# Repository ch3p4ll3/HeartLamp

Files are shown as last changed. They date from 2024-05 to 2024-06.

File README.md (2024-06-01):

# Heart Lamp
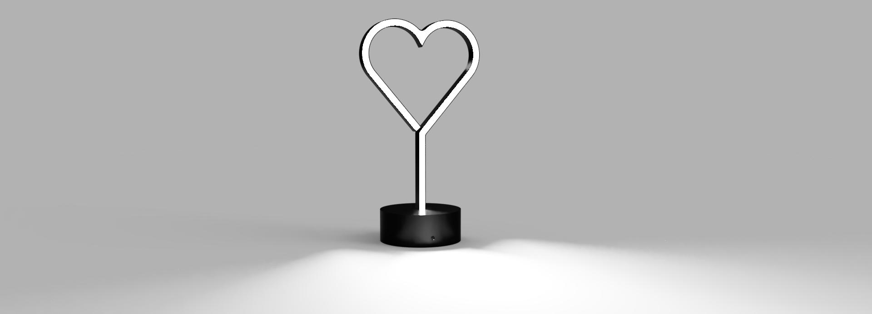
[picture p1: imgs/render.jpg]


This repository contains all the necessary files and instructions to build a heart-shaped lamp that can be controlled via WiFi and IR receiver. The lamp is based on the WEMOS D1 Mini board with WLED firmware and features a unique heart-shaped design.

# Table of contents
- [Heart Lamp](#heart-lamp)
- [Table of contents](#table-of-contents)
- [Features](#features)
- [Assembly Instructions](#assembly-instructions)
  - [3D Printing](#3d-printing)
  - [Electronics](#electronics)
    - [BOM](#bom)
    - [Schematics](#schematics)
    - [ESP Firmware](#esp-firmware)
  - [Final assembly](#final-assembly)
- [Photos](#photos)
- [Future updates](#future-updates)

# Features
- WiFi Control: Easily control the lamp via WiFi using the WLED mobile app or web interface.
- IR Receiver: Allows control of the lamp using an infrared remote control.
- Customizable: The lamp design can be customized to fit your preferences.
- Easy Assembly: Simple assembly process with detailed instructions.
- Powered via USB-C
- Supports 5V, 9V, 12V, 15V, 20V led strips
- Thanks to USB-C's PD protocol, you can select the right voltage for your LED strips(JP2). Be carefull selecting the right voltage or you might destroy the leds!

# Assembly Instructions

## 3D Printing

Print all 3 files, be careful: the stem may be too long for the printing plane, you may need to position it at 45° or print it at a slight angle. For the base, you may need to use the supports.

## Electronics

### BOM
| Part | Value | Device | Description | Link |
|---|---|---|---|---|
| C1 | 1uF | C_CHIP-0603(1608-METRIC) | Capacitor - Generic | [Link](https://it.aliexpress.com/item/1005006157020955.html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) |
| IC1 | TSOP38238 | TSOP38238 | IR Remote Receiver 38KHz 45m | [Link](https://it.aliexpress.com/item/1005005343344128.html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) |
| IC3 | CH224K | CH224K | ESSOP-10 USB ICs ROHS | [Link](https://it.aliexpress.com/item/1005006017022405.html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) |
| J1 | B4B-XH-A | B4B-XH-A | XH Connector Top Entry - 4POS | [Link](https://it.aliexpress.com/item/1005005183951296.html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) |
| J2 | B6B-XH-A_LF__SN_ | B6B-XH-A_LF__SN_ | CONN HEADER VERT 6POS 2.5MM | [Link](https://it.aliexpress.com/item/33005202279.html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) |
| JP2 | PINHD-2X3 | PINHD-2X3 | PIN HEADER | [Link](https://it.aliexpress.com/item/1005006112365881.html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) |
| PS1 | K7803JT-500R3-LB | K7803JT-500R3-LB | LINEAR REGULATOR REPLACEMENT DC Non-Isolated PoL Module DC DC Converter 1 Output 3.3V - - - 500mA 4.75V - 36V Input | [Link](https://it.aliexpress.com/item/1005004632042233.html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) |
| Q1 | IRLZ44N | IRLZ44N | MOSFET MOSFET, 55V, 41A, 22 mOhm, 32 nC Qg, Logic Level, TO-220AB | [Link](https://it.aliexpress.com/item/1005004533156263.html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) |
| Q2 | IRLZ44N | IRLZ44N | MOSFET MOSFET, 55V, 41A, 22 mOhm, 32 nC Qg, Logic Level, TO-220AB | [Link](https://it.aliexpress.com/item/1005004533156263.html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) |
| Q3 | IRLZ44N | IRLZ44N | MOSFET MOSFET, 55V, 41A, 22 mOhm, 32 nC Qg, Logic Level, TO-220AB | [Link](https://it.aliexpress.com/item/1005004533156263.html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) |
| R1 | 10k | R_AXIAL-7.2MM-PITCH | Resistor Fixed - Generic | [Link](https://it.aliexpress.com/item/1005006706426367.html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) |
| R2 | 10k | R_AXIAL-7.2MM-PITCH | Resistor Fixed - Generic | [Link](https://it.aliexpress.com/item/1005006706426367.html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) |
| R3 | 10k | R_AXIAL-7.2MM-PITCH | Resistor Fixed - Generic | [Link](https://it.aliexpress.com/item/1005006706426367.html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) |
| R4 | 10K | R_CHIP-0603(1608-METRIC) | Resistor Fixed - Generic | [Link](https://it.aliexpress.com/item/1005006157071739.html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) |
| R5 | 10k | R_CHIP-0603(1608-METRIC) | Resistor Fixed - Generic | [Link](https://it.aliexpress.com/item/1005006157071739.html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) |
| R6 | 10k | R_CHIP-0603(1608-METRIC) | Resistor Fixed - Generic | [Link](https://it.aliexpress.com/item/1005006157071739.html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) |
| R7 | 10k | R_CHIP-0603(1608-METRIC) | Resistor Fixed - Generic | [Link](https://it.aliexpress.com/item/1005006157071739.html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) |
| R8 | 1K | R_CHIP-0603(1608-METRIC) | Resistor Fixed - Generic | [Link](https://it.aliexpress.com/item/1005006157071739.html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) |
| WEMOS1 |  | WEMOS-D1-MINI | WeMos.cc | [Link](https://it.aliexpress.com/item/1005006365878568.html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) |
| USB-C |  | USB-C 6 pin connector |  | [Link](https://it.aliexpress.com/item/1005005996991234.html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) |
| LED strip |  | LED strip |  | [Link](https://it.aliexpress.com/item/1005005467162038.html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) |

### Schematics

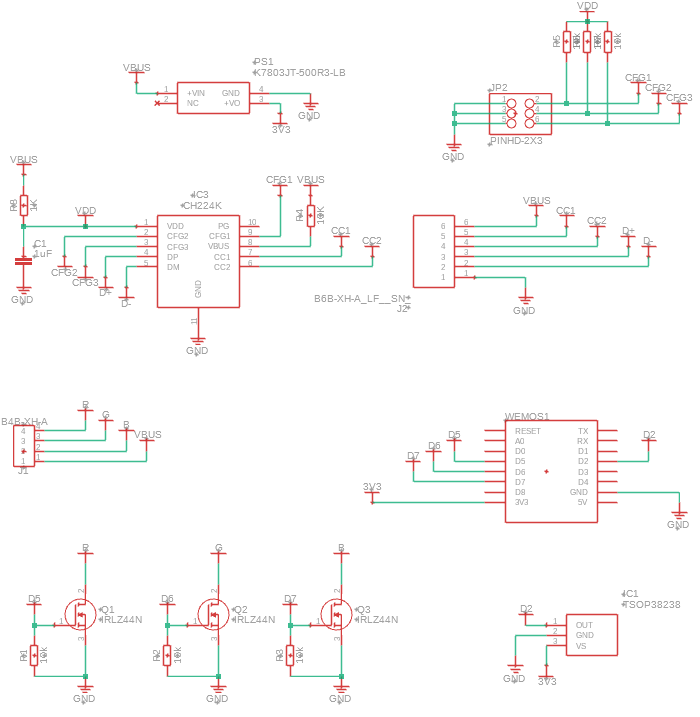
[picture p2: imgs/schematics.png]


### ESP Firmware

Follow the WLED [official guide](https://kno.wled.ge/basics/install-binary/) to install the firmware. I recommend to use the [installer site](https://install.wled.me/).

Once installed enter the WLED interface, select settings -> LED Preferences:
- On Hardware setup select `PWM RGB` and set the GPIOs to **12**, **13**, **14**
- Scroll down slightly to `IR GPIO` and set the value to **4** and **24-Key RGB**
- Click save

## Final assembly

Once you have printed all the files and soldered the various components to the PCB proceed by following the steps: 

- Gluing the LED strip inside the stem channel. Remember to cut the LED strip where indicated, the total length should be approximately 50cm
- Desolder the old connector from the LEDs and solder 4 new wires. Keep in mind what is the cable that carries the power(called 5v on the led strip)
- Crimp the XH2.54 female connector to the 4 wires keeping in mind that the top pin(the one closest to the IR sensor) should be the power supply for the LEDs. The other cables can also be crimped in another sequence, it will be possible to remap them later on the WEB interface
- (Optional) To increase the mechanical strength of the led strip near the soldering coat with hot glue
- Stick the stem inside the base, the stem should go in with a little force
- Insert the PCB inside the base and connect the LEDs
- Try turning on the lamp on by powering it through the usb-c connector and check that everything is ok
- Close the lamp by snapping the cover on. congratulations. your lamp is now working

# Photos

| | |
| - | - |
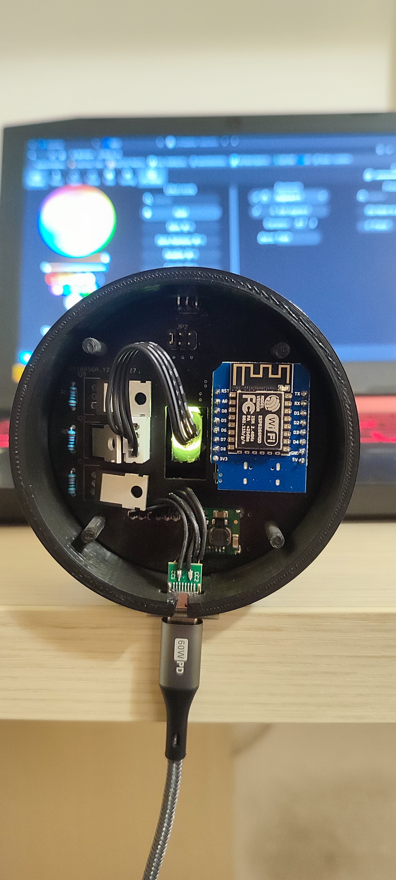
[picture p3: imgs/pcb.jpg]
pcb
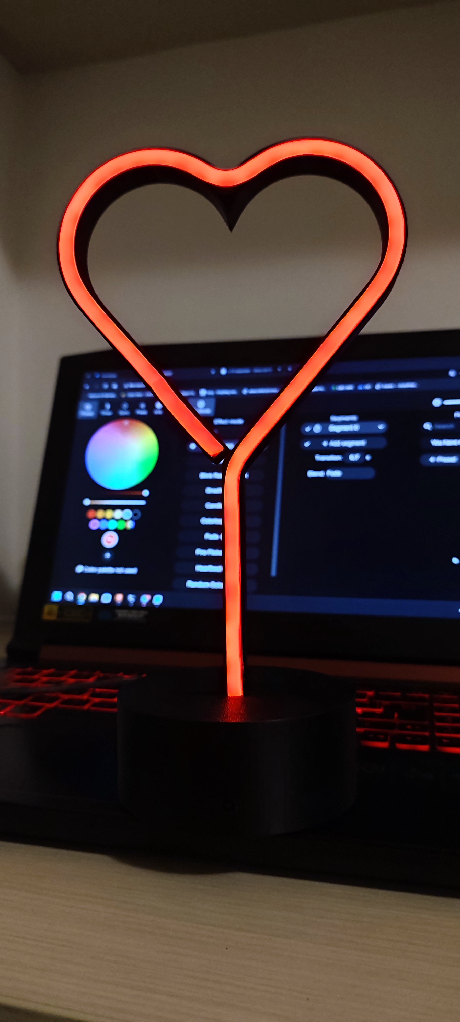
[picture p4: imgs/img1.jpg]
|  |  |
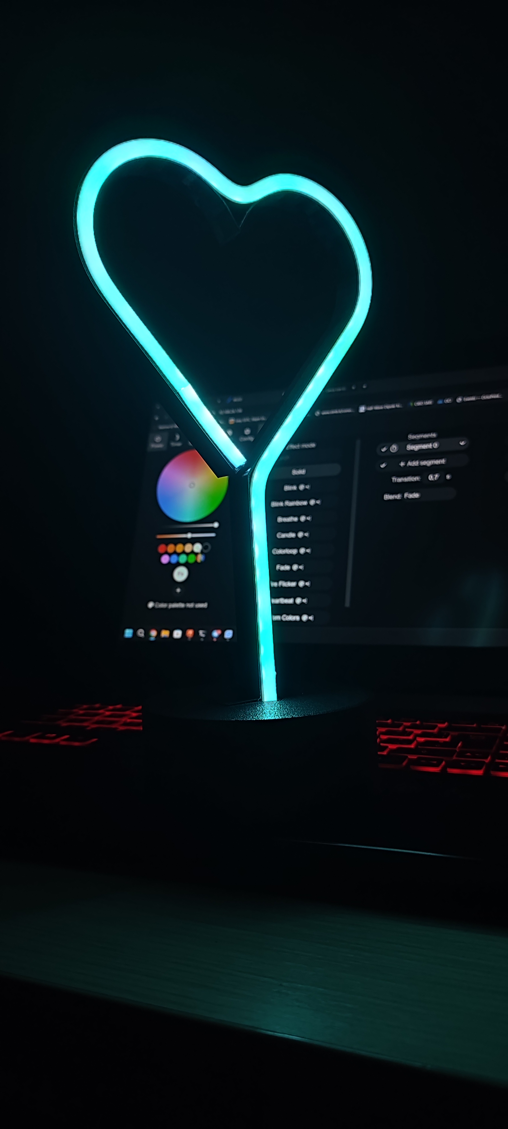
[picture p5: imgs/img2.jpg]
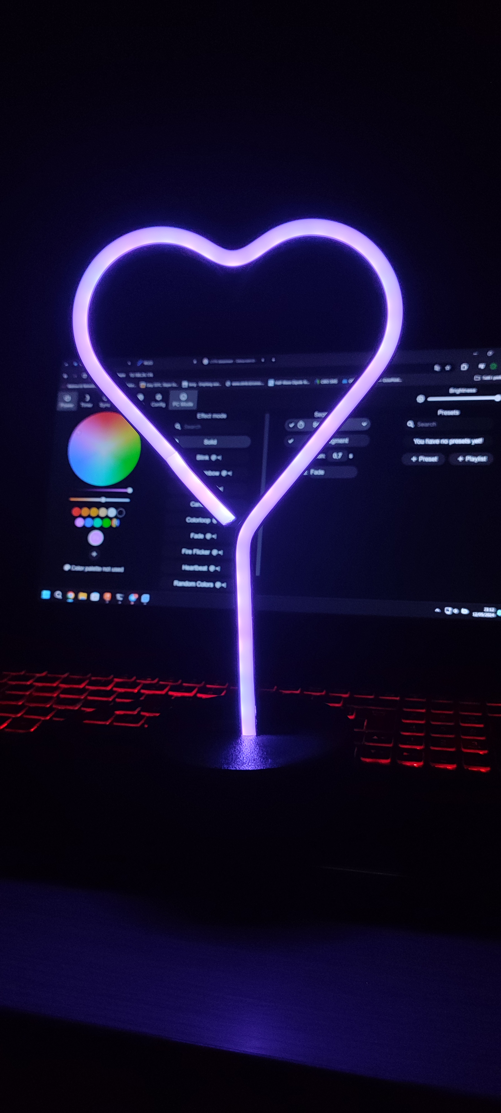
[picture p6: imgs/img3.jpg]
|  |  |

# Future updates
- Use SMD mosfets
- Create other shapes

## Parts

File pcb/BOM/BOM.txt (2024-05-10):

Partlist exported from C:/Users/vido2/AppData/Local/Temp/Neutron/ElectronFileOutput/12116/sch-47e98def-c98e-496b-b999-fb76e8bc99ff/Schema v21.sch at 11/05/2024 00:43

Part   Value            Device                   Package                        Description                                                                                                         ARROW_PART_NUMBER ARROW_PRICE-STOCK                                                                CATEGORY  DESCRIPTION                                                                                                         DSECRIPTION                                               HEIGHT MANUFACTURER           MANUFACTURER_NAME                MANUFACTURER_PART_NUMBER MOUSER_PART_NUMBER MOUSER_PRICE-STOCK                                                                                     MPN              OPERATING_TEMP OPERATING_TEMPERATURE PART_STATUS PITCH            RATING ROHS_COMPLIANCE  ROHS_COMPLIANT SERIES  SUB-CATEGORY       SUB_CATEGORY            THERMALLOSS TOLERANCE TYPE                                                        VOLTAGE_RATING
C1     1uF              C_CHIP-0603(1608-METRIC) CAPC1608X85                    Capacitor - Generic                                                                                                                                                                                                    Capacitor                                                                                                                                                                                                                                                                                                                                                                                                                                                                                                                                                                                                                                                                              
IC1    TSOP38238        TSOP38238                TSOP38238                      IR Remote Receiver 38KHz 45m                                                                                        TSOP38238         https://www.arrow.com/en/products/tsop38238/vishay?region=nac                              IR Remote Receiver 38KHz 45m                                                                                                                                                  mm                            Vishay                           TSOP38238                782-TSOP38238      https://www.mouser.co.uk/ProductDetail/Vishay-Semiconductors/TSOP38238?qs=RzxYCzJDjPVjpHVZS582Ng%3D%3D                                                                                                                                                                                                                                                                              
IC3    CH224K           CH224K                   SOP100P600X180-11N             ESSOP-10 USB ICs ROHS                                                                                                                                                                                                            ESSOP-10 USB ICs ROHS                                                                                                                                                         1.8mm                         WCH                              CH224K                                                                                                                                                                                                                                                                                                                                                                                                                          
J1     B4B-XH-A         B4B-XH-A                 B4B-XH-A                       XH Connector Top Entry - 4POS                                                                                                                                                                                          Header                                                                                                                        Connector Header Through Hole 4 position 0.098" (2.50mm)         JST Sales America Inc.                                                                                                                                                                                     B4B-XH-A(LF)(SN)                -25 C to 85 C         ACTIVE      0.098" (2.50mm)         ROHS3 Compliant                 XH                         Rectangular Connectors                        Header, Male Pin, Board to Cable/Wire, Through Hole                       
J2     B6B-XH-A_LF__SN_ B6B-XH-A_LF__SN_         SHDR6W64P0X250_1X6_1740X575X70 CONN HEADER VERT 6POS 2.5MM                                                                                         B6B-XH-A(LF)(SN)  https://www.arrow.com/en/products/b6b-xh-a-lf-sn/jst-manufacturing?region=europe           CONN HEADER VERT 6POS 2.5MM                                                                                                                                                   7mm                           JST (JAPAN SOLDERLESS TERMINALS) B6B-XH-A(LF)(SN)                                                                                                                                                                                                                                                                                                                                                                                                                
JP2    PINHD-2X3        PINHD-2X3                2X03                           PIN HEADER                                                                                                                                                                                                             Headers   Header, Straight, 2x3 Position                                                                                                                                                       Generic                                                                                                                                                                                                    Generic                         Generic               Active      0.100" (2.54mm)         Generic                         Generic Headers, Male Pins                                               Board to Board or Cable, Unshrouded, Through Hole, Straight               
PS1    K7803JT-500R3-LB K7803JT-500R3-LB         K7803JT500R3LB                 LINEAR REGULATOR REPLACEMENT DC Non-Isolated PoL Module DC DC Converter 1 Output 3.3V - - - 500mA 4.75V - 36V Input                                                                                                              LINEAR REGULATOR REPLACEMENT DC Non-Isolated PoL Module DC DC Converter 1 Output 3.3V - - - 500mA 4.75V - 36V Input                                                           4.5mm                         Mornsun Power                    K7803JT-500R3-LB                                                                                                                                                                                                                                                                                                                                                                                                                
Q1     IRLZ44N          IRLZ44N                  TO254P469X1042X1967-3P         MOSFET MOSFET, 55V, 41A, 22 mOhm, 32 nC Qg, Logic Level, TO-220AB                                                                                                                                                                MOSFET MOSFET, 55V, 41A, 22 mOhm, 32 nC Qg, Logic Level, TO-220AB                                                                                                             4.69mm                        Infineon                         IRLZ44N                  N/A                https://www.mouser.co.uk/ProductDetail/Infineon-IR/IRLZ44N?qs=zO0nedAqnNIAphT7g5cSVQ%3D%3D                                                                                                                                                                                                                                                                                          
Q2     IRLZ44N          IRLZ44N                  TO254P469X1042X1967-3P         MOSFET MOSFET, 55V, 41A, 22 mOhm, 32 nC Qg, Logic Level, TO-220AB                                                                                                                                                                MOSFET MOSFET, 55V, 41A, 22 mOhm, 32 nC Qg, Logic Level, TO-220AB                                                                                                             4.69mm                        Infineon                         IRLZ44N                  N/A                https://www.mouser.co.uk/ProductDetail/Infineon-IR/IRLZ44N?qs=zO0nedAqnNIAphT7g5cSVQ%3D%3D                                                                                                                                                                                                                                                                                          
Q3     IRLZ44N          IRLZ44N                  TO254P469X1042X1967-3P         MOSFET MOSFET, 55V, 41A, 22 mOhm, 32 nC Qg, Logic Level, TO-220AB                                                                                                                                                                MOSFET MOSFET, 55V, 41A, 22 mOhm, 32 nC Qg, Logic Level, TO-220AB                                                                                                             4.69mm                        Infineon                         IRLZ44N                  N/A                https://www.mouser.co.uk/ProductDetail/Infineon-IR/IRLZ44N?qs=zO0nedAqnNIAphT7g5cSVQ%3D%3D                                                                                                                                                                                                                                                                                          
R1     10k              R_AXIAL-7.2MM-PITCH      RESAD724W46L381D178B           Resistor Fixed - Generic                                                                                                                                                                                               Resistor                                                                                                                                                                                                                                                                                                                                                                                                                                                                                                                                    Fixed                                                                                                                                      
R2     10k              R_AXIAL-7.2MM-PITCH      RESAD724W46L381D178B           Resistor Fixed - Generic                                                                                                                                                                                               Resistor                                                                                                                                                                                                                                                                                                                                                                                                                                                                                                                                    Fixed                                                                                                                                      
R3     10k              R_AXIAL-7.2MM-PITCH      RESAD724W46L381D178B           Resistor Fixed - Generic                                                                                                                                                                                               Resistor                                                                                                                                                                                                                                                                                                                                                                                                                                                                                                                                    Fixed                                                                                                                                      
R4     10K              R_CHIP-0603(1608-METRIC) RESC1608X60                    Resistor Fixed - Generic                                                                                                                                                                                               Resistor                                                                                                                                                                                                                                                                                                                                                                                                                                                                                                                                    Fixed                                                                                                                                      
R5     10k              R_CHIP-0603(1608-METRIC) RESC1608X60                    Resistor Fixed - Generic                                                                                                                                                                                               Resistor                                                                                                                                                                                                                                                                                                                                                                                                                                                                                                                                    Fixed                                                                                                                                      
R6     10k              R_CHIP-0603(1608-METRIC) RESC1608X60                    Resistor Fixed - Generic                                                                                                                                                                                               Resistor                                                                                                                                                                                                                                                                                                                                                                                                                                                                                                                                    Fixed                                                                                                                                      
R7     10k              R_CHIP-0603(1608-METRIC) RESC1608X60                    Resistor Fixed - Generic                                                                                                                                                                                               Resistor                                                                                                                                                                                                                                                                                                                                                                                                                                                                                                                                    Fixed                                                                                                                                      
R8     1K               R_CHIP-0603(1608-METRIC) RESC1608X60                    Resistor Fixed - Generic                                                                                                                                                                                               Resistor                                                                                                                                                                                                                                                                                                                                                                                                                                                                                                                                    Fixed                                                                                                                                      
WEMOS1                  WEMOS-D1-MINI            WEMOS-D1-MINI                  WeMos.cc

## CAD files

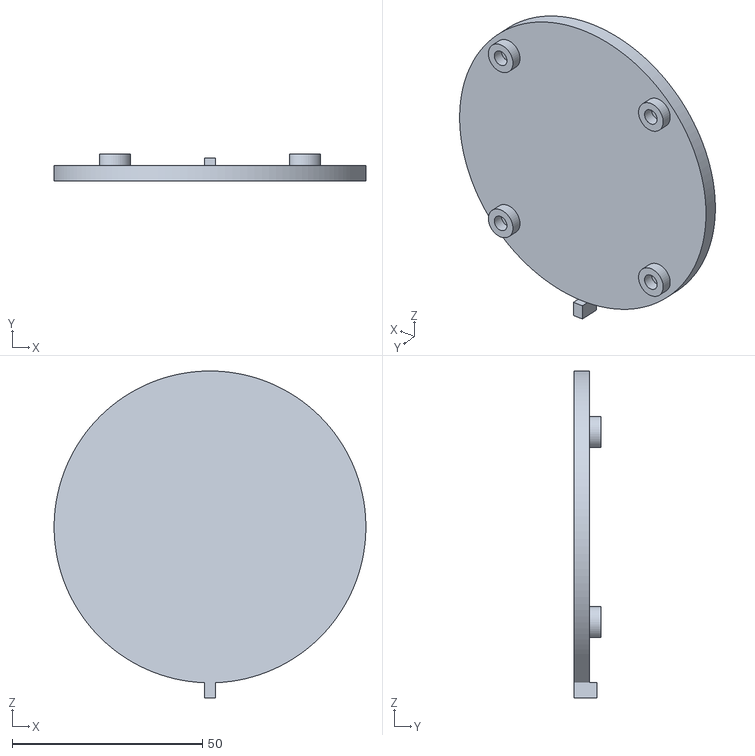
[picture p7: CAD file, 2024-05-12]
3d models/stl/Cover V2 - USB C v6.stl
82.0 x 7.00 x 86.0

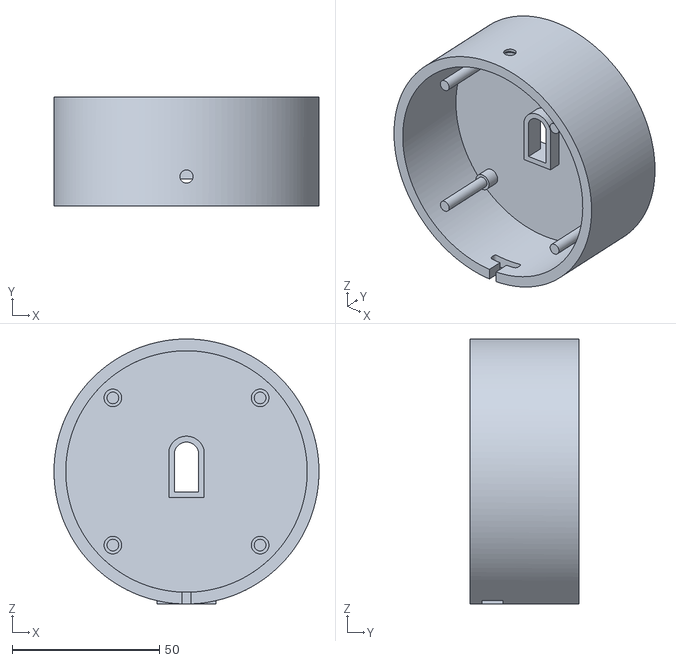
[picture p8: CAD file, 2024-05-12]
3d models/stl/Base V2 - USB C v7.stl
90.0 x 37.0 x 90.0

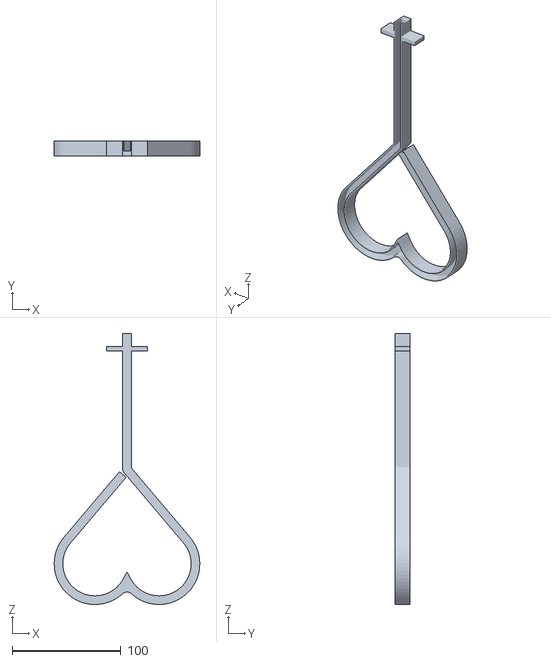
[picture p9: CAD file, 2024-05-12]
3d models/stl/Stem v21.stl
133.8 x 13.8 x 249.1

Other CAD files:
3d models/Base V2 - USB C v7.f3d
3d models/Cover V2 - USB C v6.f3d
3d models/Stem v21.f3d
pcb/Progettazione elettronica v57.f3z

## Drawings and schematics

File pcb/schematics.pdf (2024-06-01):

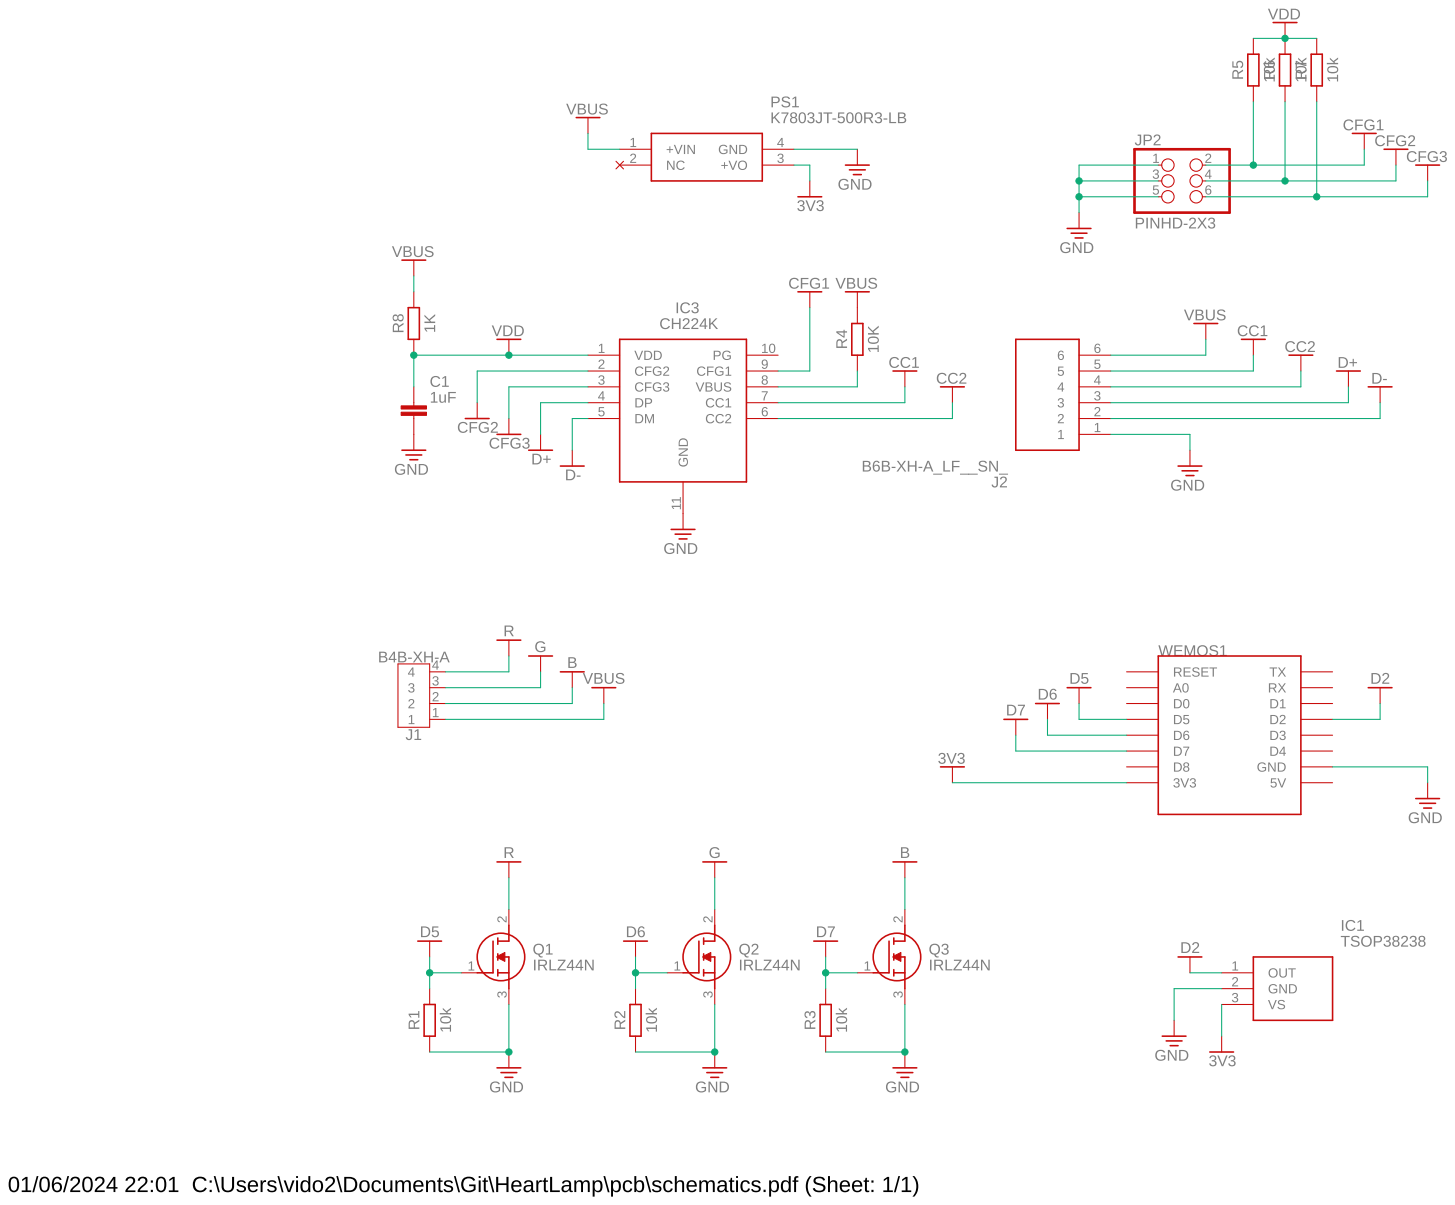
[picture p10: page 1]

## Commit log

2024-05-12 update 3d files
    [Base V2 - USB C v6.f3d, Base V2 - USB C v6.stl, Base V2 - USB C v7.f3d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]
2024-06-01 fix IR receiver pin
    [Progettazione elettronica v57.f3z]
